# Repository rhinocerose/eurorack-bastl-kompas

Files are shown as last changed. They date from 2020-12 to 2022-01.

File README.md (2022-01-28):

# Cloned from https://git.sr.ht/~philomates/kompas

# SMD version of Bastl Kompas

As an attempt to learn kicad I decided to take the open source Bastl Kompas eurorack module, which is a 5hp through-hole soldering project, and redesign it as a 4hp SMD soldering project.

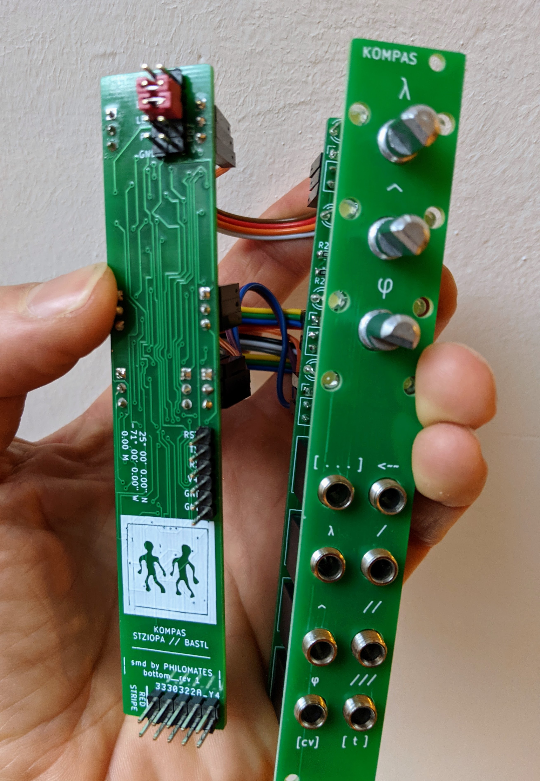
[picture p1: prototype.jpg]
prototype


## Bill of Materials

[Mouser BOM](https://www.mouser.de/ProjectManager/ProjectDetail.aspx?AccessID=1936c8aad0) or find the excel file in this repository.

Parts should come out to be below 20 euros.

## hardware modifications

The SMD version has a different pin mapping which should be described in the code. The reason for this is the following:

### exposing MOSI/MISO/SCK/SS for on-pcb bootloader flashing

With the original Kompas you can take the ATMEGA328 chip, place it on a breadboard, and flash the Arduino bootloader onto it by wiring the MOSI/MISO/SCK/SS pins up to a normal Arduino or another ISP programmer.
With the SMD ATMEGA328-AU chip, you can't put it on a breadboard, so the normal way for flashing these with the arduino bootloader

### exposing SDA/SCL pins as extension pins for integration with sensors

This project is based off the ATMEGA328-AU chip, which has 2 additional analog input pins when compared to the ATMEGA328-P that the Bastl Kompas uses.

### different pins

It is easiest to check the code or schematics. This was done to cleanly expose the ICSP headers and serial pins.

### more exposed pins for extensions

## hardware resources

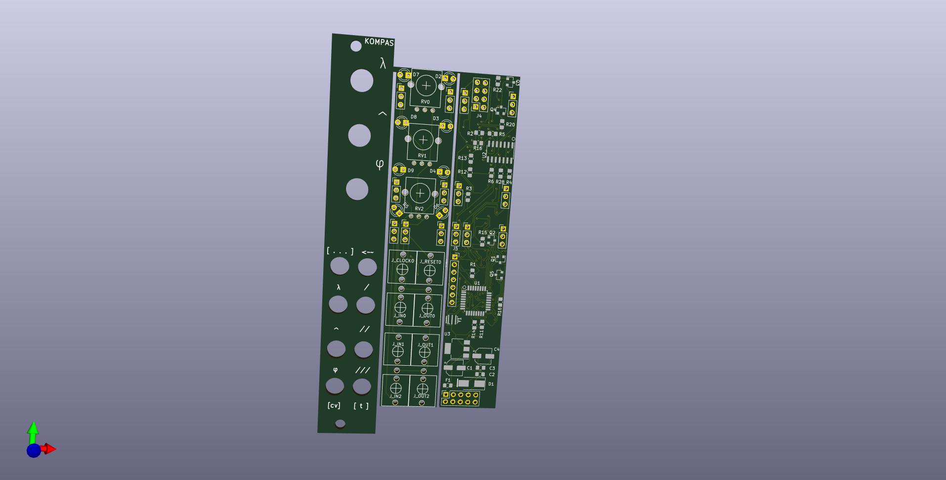
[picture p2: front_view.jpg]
front_view


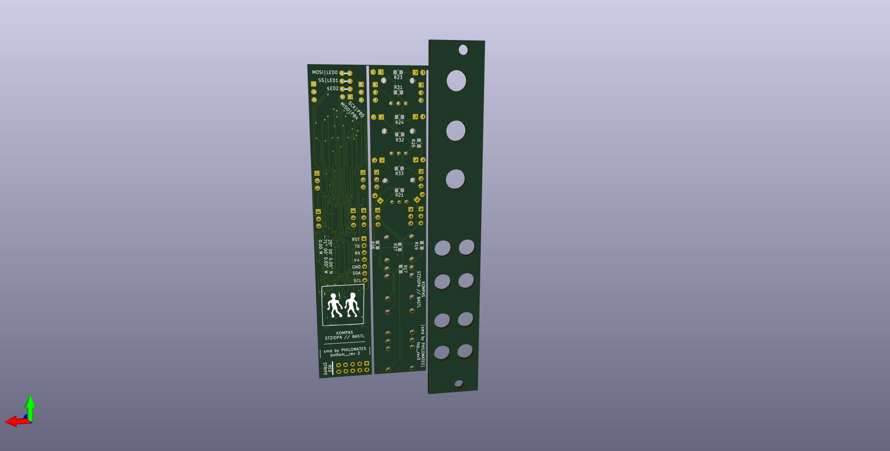
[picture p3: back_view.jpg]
back_view


[schematic found here](schematic.pdf)

The design was done in Kicad. Also provided are the gerber files for PCB fabrication

## alternative firmwares

See `code/` directory.

### window comparator

Essentially an attempt to be half of a Joranalogue 'Compare 2' module. Works alright and the top pot is mapped to a sample rate reduction thing which gives funky results.

### probabilistic latch / burst generator

Dual latch + single burst generator. The latches have probability modulation for likelihood of un/setting.

## CHANGELOG

### rev 3 (untested)

 - fixed up some alignments in the panel (I think)
 - removed second fuse (reducing parts cost by a 1 euro) because few people would use it

### rev 2
 - fixed missing connection issues in rev 1
 - ICSP header pins exposed for bootloader flashing
 - SDA/SCL serial line pins exposed for interfacing with other components

### rev 1
 - direct copy of Bastl version but in SMD.
 - has some bugs that require custom connections after.
 - flashing arduino bootloader requires soldering jumpers straight to SMD components.

## License

The original (Bastl Kompas)[https://github.com/bastl-instruments/kompas] is CC-BY-SA and this work perpetuates that.

Utmost thanks to the original designers for making their work available!

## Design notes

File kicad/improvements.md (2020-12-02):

expose for programming:
MOSI (PB3) 15
MISO (PB4) 16
SCK (PB5) 17
RESET (PC6) 29

expose for DAC
SS (PB2)

PB2 -- out1
PB3 -- out0
PB4 -- reset
PB5 -- clock

reset could go to PB0
clock could go to PD7
could switch outs with leds so you can choose between DAC or LEDs
could expose ADC6 (19) and ADC7 (22) for extra analog ins

PWM pins
PB1
PB2
PB3
PD3
PD5
PD6

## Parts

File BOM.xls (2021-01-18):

KOMPAS SMD
Mouser No | Mfr. No | Manufacturer | Customer No | Description | RoHS | Lifecycle | Order Qty. | Price (EUR) | Ext.: (EUR)
667-EEE-1EA100SR | EEE-1EA100SR | Panasonic | kC1, C4 | Aluminium Electrolytic Capacitors - SMD 10uF 25V | RoHS Compliant |  | 2 | 0,195 € | 0,39 €
80-C0805C104K5R | C0805C104K5RACTU | KEMET | kC2, C3 | Multilayer Ceramic Capacitors MLCC - SMD/SMT 50V 0.1uF X7R 0805 10% | RoHS Compliant |  | 2 | 0,203 € | 0,41 €
660-RK73H2ATTD1002F | RK73H2ATTD1002F | KOA Speer | k18,20,22 | Thick Film Resistors - SMD 1/4W 10K OHM 1% | RoHS Compliant |  | 3 | 0,101 € | 0,30 €
595-LM7805MPX/NOPB | LM7805MPX/NOPB | Texas Instruments | k | Linear Voltage Regulators | RoHS Compliant |  | 1 | 1,12 € | 1,12 €
621-S1KB-F | S1KB-13-F | Diodes Incorporated | kD1 | Rectifiers 800V 1A | RoHS Compliant By Exemption |  | 1 | 0,296 € | 0,30 €
621-MMBT3904-F | MMBT3904-7-F | Diodes Incorporated | k | Bipolar Transistors - BJT 40V NPN SS Trans 60Vceo 6Vebo 200mA | RoHS Compliant |  | 5 | 0,102 € | 0,51 €
579-MCP6004T-I/SL | MCP6004T-I/SL | Microchip | k | Operational Amplifiers - Op Amps Quad 1.8V 1MHz | RoHS Compliant |  | 1 | 0,373 € | 0,37 €
81-CSTNE16M0VH3L000R | CSTNE16M0VH3L000R0 | Murata | k | Resonators 16.0000MHz 15pF SMD CHP Resntr Tol 0.07% |  |  | 1 | 0,356 € | 0,36 €
576-0805L010/24YR | 0805L010/24YR | Littelfuse | k | Resettable Fuses - PPTC 0.10A 24V 0805 | RoHS Compliant |  | 1 | 1,58 € | 1,58 €
667-ERJ-6RED1004V | ERJ-6RED1004V | Panasonic | k2,3,28 | Thick Film Resistors - SMD 0805 Resistor 0.5% 100ppm 1MOhm |  |  | 3 | 0,178 € | 0,53 €
667-ERJ-6RBD1001V | ERJ-6RBD1001V | Panasonic | k11,12,14,15,17,19,21 | Thick Film Resistors - SMD 0805 1Kohms 0.5% AEC-Q200 | RoHS Compliant By Exemption |  | 15 | 0,065 € | 0,98 €
645-521-9901-802F | 521-9901-802F | Dialight | k | Standard LEDs - Through Hole White Octo-Binned | RoHS Compliant |  | 10 | 0,332 € | 3,32 €
556-ATMEGA328-AUR | ATMEGA328-AUR | Microchip | k | 8-bit Microcontrollers - MCU AVR 32K FLSH 1K EE2K SRAM-20MHz IND | RoHS Compliant |  | 1 | 1,61 € | 1,61 €
538-22-28-4360 | 22-28-4360 | Molex | k | Headers & Wire Housings 36P 1 ROW VERT HDR | RoHS Compliant |  | 2 | 0,686 € | 1,37 €
855-M7582-05 | M7582-05 | Harwin | k | Headers & Wire Housings JUMPER SOCKET OPEN TOP BLACK | RoHS Compliant |  | 4 | 0,169 € | 0,68 €
710-61301011821 | 61301011821 | Wurth Elektronik | k | Headers & Wire Housings WR-PHD 2.54mm 10Pin Socket Header | RoHS Compliant |  | 1 | 0,559 € | 0,56 €
660-RN732ATTD1003D25 | RN732ATTD1003D25 | KOA Speer | k1,4,5,6,13,16 | Thin Film Resistors - SMD 100kOhm 0805 0.5% 25 ppm 100mW 100V | RoHS Compliant |  | 6 | 0,181 € | 1,09 €
858-P0915NEC15BR100K | P0915N-EC15BR100K | TT Electronics |  | Potentiometers 9mm 100Kohm | RoHS Compliant |  | 3 | 1,02 € | 3,06 €

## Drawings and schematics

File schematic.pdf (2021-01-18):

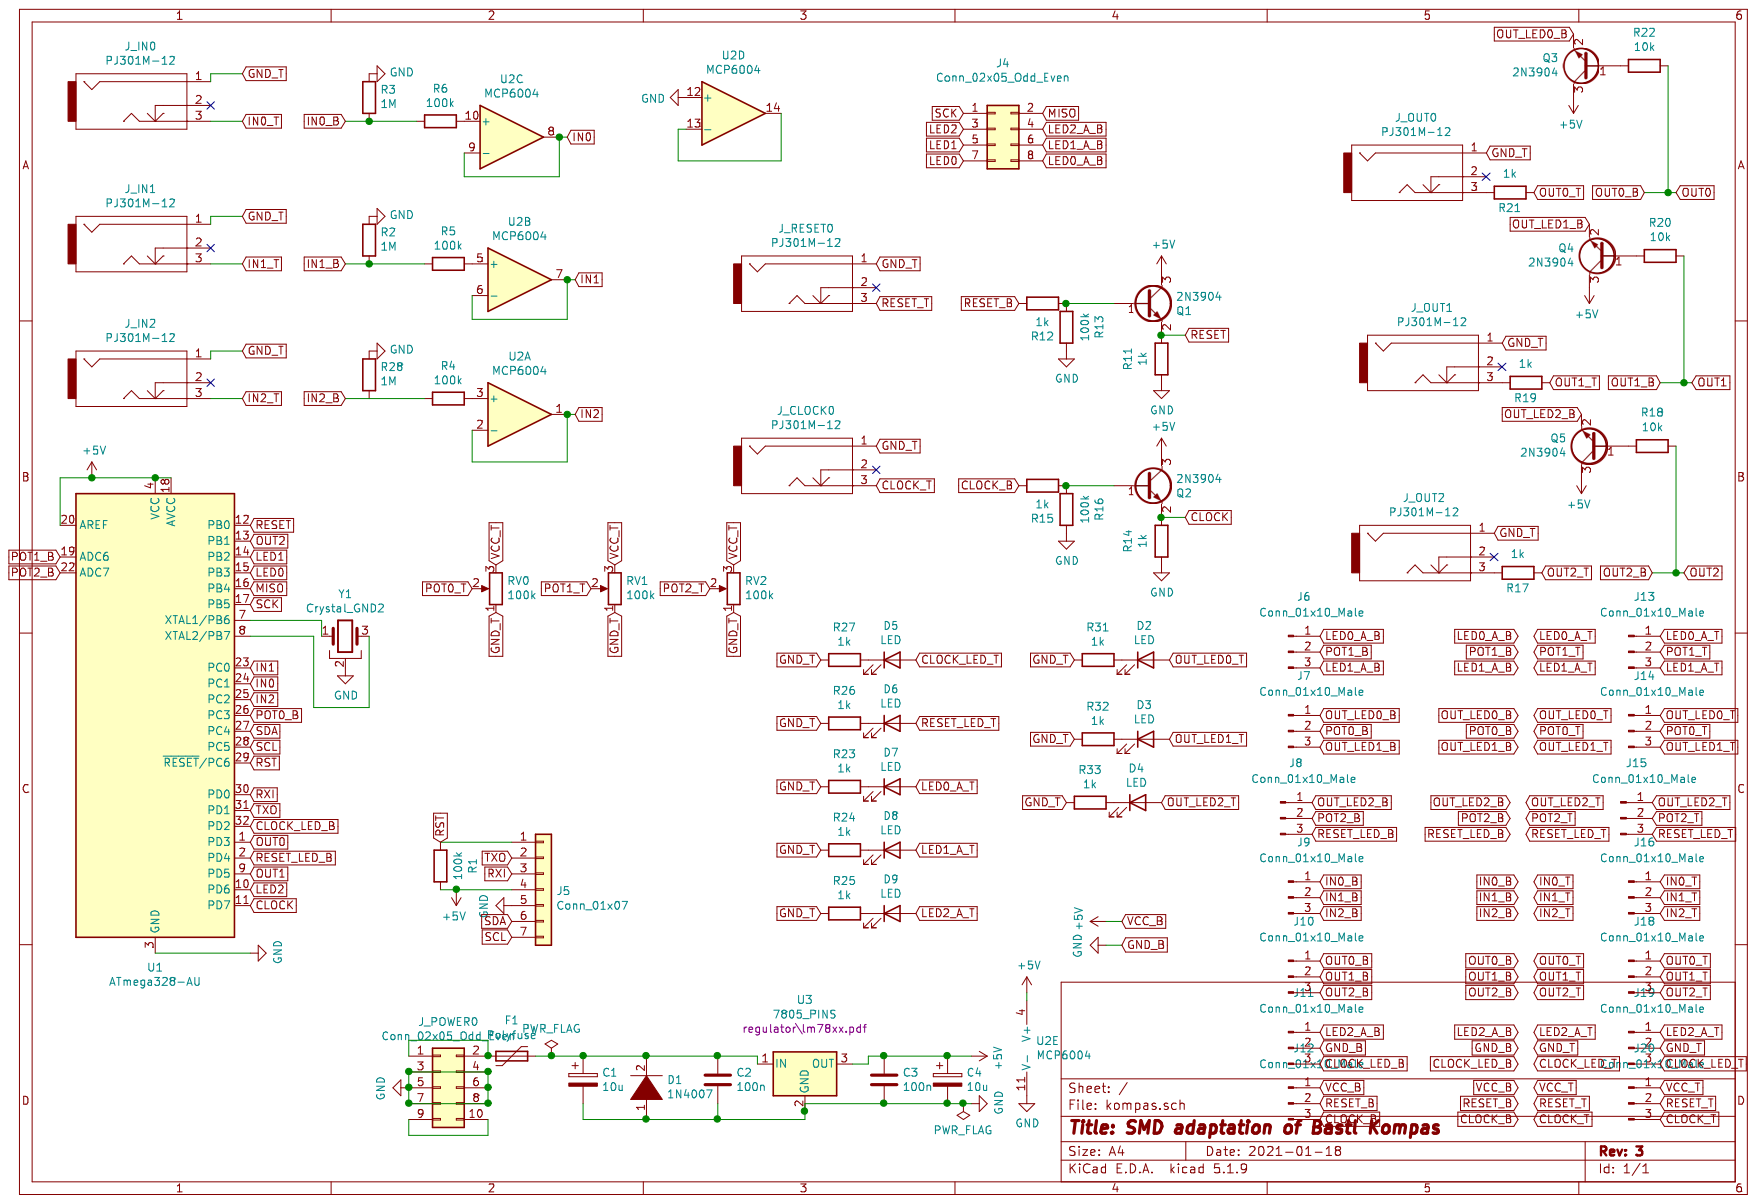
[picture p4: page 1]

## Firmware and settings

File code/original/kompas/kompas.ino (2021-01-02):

/*
 * Firmware for stziopa/bastl-instruments Kompas
 * licensed under CC-BY-SA by Stefano Manconi 02-09-2019
 */

/*
 * KOMPAS
 *
 *this tool is
 *the outcome
 *of the environment
 *we are in and
 *is inspired by a
 *non-linear approach
 *to music and life -
 *don't build any
 *expectations choose
 *your direction and
 *discover new paths
 *
*/

//NAVIGATION BEGINS:......
#include <EEPROM.h>
#include "hardware.h"
#include "definitions.h"
#include "variables.h"

void setup() {
  Serial.begin(9600);
  bootMode = false;
  //check for the first startup
  if(!isEEPROMvalid()){
    formatFactory();
    delay(100);
  }

  loadPreset();

  // set pins PB7, PB6, PB3 (led0), PB2 (led1), PB1 (out2) as outputs,
  // PB5, PB4, PB0 as input
  DDRB = B11001110;
  /* PORTB|B00000001; */
  // PB0 internal pullup resistor
  /* PINB|=B00000001; */

  // set PD7 as input
  DDRD= DDRD & B01111111;
  // set pins PD6, PD5, PD4, PD3, PD2 as outputs
  // leaves PD1 and PD0 as default (ftdi)
  DDRD = DDRD | B01111100;
  /* PORTD|B00000000; */
  // PD7 High
  /* PIND|=B10000000; */

  pinMode(clock_led, OUTPUT);
  pinMode(reset_led, OUTPUT);

  pinMode(led0, OUTPUT);
  pinMode(led1, OUTPUT);
  pinMode(led2, OUTPUT);

  randomSeed(analogRead(A5));

  //BOOTMODE (close jumper in between PB0 and GND before startup)
  if(!bootPin) {
    bootMode = true;
    loadPreset();

    pot0 = analogRead(A3);
    pot1 = analogRead(A4);
    pot2 = analogRead(A5);
    prevPot0 = pot0;
    prevPot1 = pot1;
    prevPot2 = pot2;

  } else {
    bootMode = false;
    loadPreset();
  }

  while(bootMode) {
    pot0 = analogRead(A3);
    pot1 = analogRead(A4);
    pot2 = analogRead(A5);

    if(pot0 > (prevPot0 + 9) || pot0 < (prevPot0 - 9)) {
      prevPot0 = pot0;
      EEPROM.update(addr, 0x0);
    }
    if(pot1 > (prevPot1 + 9) || pot1 < (prevPot1 - 9)) {
      prevPot1 = pot1;
      EEPROM.update(addr, 0x1);
    }
    if(pot2 > (prevPot2 + 9) || pot2 < (prevPot2 - 9)) {
      prevPot2 = pot2;
      EEPROM.update(addr, 0x2);
    }

  loadPreset();
  switch(trigPreset) {
      case 0:
        PORTD=PORTD&B11010111; // set Out{0,1} low
        PORTB=PORTB&B11111101; // set Out2 low
        PIND|=B00001000; // set Out0 high
        break;
      case 1:
        PORTD=PORTD&B11010111; // set Out{0,1} low
        PORTB=PORTB&B11111101; // set Out2 low
        PIND|=B00100000; // set Out1 high
        break;
      case 2:
        PORTD=PORTD&B11010111; // set Out{0,1} low
        PINB|=B00000010; // set Out2 high
        break;
  }
  //delay(100);
  //Serial.println(bootMode);
  }
  Serial.println(trigLength);
}

void loop() {

  //enables clock and reset functions
  deClock();
  deReset();

  generateArray0();
  generateArray2();
  generateArray1();
  //comment out for CV
  //deReset0();
  //deReset1();
  //deReset2();

  //global & individual resets
  if(resetState) {
    lastReset = millis();
    digitalWrite(reset_led, HIGH);
    step0 = (length0 - 1);
    step1 = (length1 - 1);
    step2 = (length2 - 1);
  }

  //un-comment for turning CV inputs into individual reset inputs!
  /*
  if(reset0State) {
    lastReset0 = millis();
    digitalWrite(led0, HIGH);
    step0 = (length0 - 1);
  }
  if(reset1State) {
    lastReset1 = millis();
    digitalWrite(led1, HIGH);
    step1 = (length1 - 1);
  }
  if(reset2State) {
    lastReset2 = millis();
    digitalWrite(led2, HIGH);
    step2 = (length2 - 1);
  }  */

//for each incoming clock detected:
  if(clockState) {
    lastClock = millis();
    step0++;
    step1++;
    step2++;

    digitalWrite(clock_led, HIGH);

    if(step0 > (length0 - 1)) {
      step0 = 0;
    }
    if(step1 > (length1 - 1)) {
      step1 = 0;
    }
    if(step2 > (length2 - 1)) {
      step2 = 0;
    }

    //current step number
    pos0 = step0;
    pos1 = step1;
    pos2 = step2;


    //read CV input Longitude, Altitude, Latitude
    cv0 = analogRead(A0);
    cv1 = analogRead(A1);
    cv2 = analogRead(A2);



    if(cv0 > 1011) {
      stepValue0 = 0;
      stepValue0 = 1;
      digitalWrite(led0, HIGH);
    } else {
      stepValue0 = 0;
      stepValue0 = patternArray0[pos0];
    }

    if(cv1 > 1011) {
      stepValue1 = 0;
      stepValue1 = 1;
      digitalWrite(led1, HIGH);
    } else {
      stepValue1 = 0;
      stepValue1 = patternArray1[pos1];
    }

    if(cv2 > 1011) {
      stepValue2 = 0;
      stepValue2 = 1;
      digitalWrite(led2, HIGH);
    } else {
      stepValue2 = 0;
      stepValue2 = patternArray2[pos2];
    }

    if(stepValue0) {
      PIND|=B00001000; // set Out0 high
    }
    if(stepValue1) {
      PIND|=B00100000; // set Out1 high
    }
    if(stepValue2) {
      PINB|=B00000010; // set Out2 high
    }

    //read values from pots Longitude, Altitude, Latitude
    pot0 = analogRead(A3);
    pot1 = analogRead(A6);
    pot2 = analogRead(A7);

    //add CV to pot value (offset)
    prob0 = (pot0 + cv0);
    prob1 = (pot1 + cv1);
    prob2 = (pot2 + cv2);
    Serial.println(String(cv0) + "\t" + String(cv1) + "\t" + String(cv2)
    + "\t" + String(pot0) + "\t" + String(pot1) + "\t" + String(pot2));


    noSteps0 = map(prob0, 1, 1021, 1, 8);

  }

  // sets the end of trigger signals and clock LED
  if(millis() >= lastClock + trigLength) {
    PORTD=PORTD&B11010111; // set Out{0,1} low
    PORTB=PORTB&B11111101; // set Out2 low
    digitalWrite(clock_led, LOW);
  }

  // LONGITUDE randomarray over euclidean
    if(prob0 > (prevProb0 + 2) || prob0 < (prevProb0 - 2)) {
      prevProb0 = prob0;

    if(prob0 > 2) {
    if(prob0 < 1011) {
      generate0 = true;

      patternArray0[0] = 1;
      for(int i=1; i<(length0/2); i++) {
          if(((i*noSteps0)%(length0/2)) < noSteps0) {
            patternArray0[i] = 1;
            if((randomArray0[i] < prob0) & patternArray0[i]) {
              patternArray0[i] = 1;
            } else {
              patternArray0[i] = 0;
            }
          } else {
            patternArray0[i] = 0;
          }
        }
      for(int i=(length0/2); i<length0; i++) {
          if(((i*noSteps0)%(length0/2)) < noSteps0) {
            patternArray0[i] = 1;
            if((randomArray0[i] < prob0) & patternArray0[i]) {
              patternArray0[i] = 1;
            } else {
              patternArray0[i] = 0;
            }
          } else {
            patternArray0[i] = 0;
          }
        }

      }

      } else {
          for(int i=0; i < length0; i++) {
          patternArray0[i] = 0;
          }
          }

      if(pot0 > 1011) {
        for(int i=0; i < length0; i++) {
          patternArray0[i] = 1;
          }
      }

}


  // LATITUDE pseudo-random array
    if(prob2 > (prevProb2 + 2) || prob2 < (prevProb2 - 2)) {
      prevProb2 = prob2;

        if(prob2 > 2) {
         if(prob2 < 1011) {
         generate2 = true;

        for(int i=0; i < length2; i++) {
          if(randomArray2[i] < (prob2)) {
              patternArray2[i] = 1;
            } else {
              patternArray2[i] = 0;
            }
          }

          //makes sure at least one step will be filled
          int rnd2 = random(length2);
          patternArray2[rnd2] = 1;

         }

      } else {
          for(int i=0; i < length2; i++) {
          patternArray2[i] = 0;
          }
          prevProb2 = 0;
        }

         if(pot2 > 1011) {
        for(int i=0; i < length2; i++) {
          patternArray2[i] = 1;
          }
      }
  }


  // ALTITUDE if Long == Lat - it makes a pattern based on matching steps
    if(prob1 > (prevProb1 + 2) || prob1 < (prevProb1 - 2)) {
      prevProb1 = prob1;

       if(prob1 > 2) {
       if(prob1 < 1011) {
        generate1 = true;

        for(int i=0; i < length1; i++) {
            if(patternArray0[i] == patternArray2[i]) {
              if(randomArray1[i] < prob1) {
                patternArray1[i] = 1;
              } else {
                patternArray1[i] = 0;
              }
            } else patternArray1[i] = 0;
          }

        for(int i=0; i < length1; i++) {
            if(patternArray0[i] == patternArray2[i]) {
                patternArray1[i] = 1;
                i = length1;
              }
            }

        }

       } else {
          for(int i=0; i < length1; i++) {
            patternArray1[i] = 0;
          }
        }

         if(pot1 > 1011) {
        for(int i=0; i < length1; i++) {
          patternArray1[i] = 1;
          }
      }
}


  //turn off reset LED
  if(millis() >= lastReset + trigLength) {
    digitalWrite(reset_led, LOW);
  }
  //turn off coordinate LEDs
  if(millis() >= lastGenerate0 + trigLength) {
  digitalWrite(led0, LOW);
  }
  if(millis() >= lastGenerate1 + trigLength) {
    digitalWrite(led1, LOW);
  }
  if(millis() >= lastGenerate2 + trigLength) {
    digitalWrite(led2, LOW);
  }
}

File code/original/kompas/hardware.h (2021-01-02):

#ifndef _HARDWARE_H_
#define _HARDWARE_H_

//Kompas Hardware

#define clockIn PIND&B10000000
#define resetIn PINB&B00000001

//un-comment for turning CV inputs into individual reset inputs
//#define resetIn0 PINC&B00000001
//#define resetIn1 PINC&B00000010
//#define resetIn2 PINC&B00000100

//Port mapping for outputs Longitude, altitude, latitude
#define trigOut0 PIND&B00001000 // PD3
#define trigOut1 PIND&B00100000 // PD5
#define trigOut2 PINB&B00000010 // PB1

//unused pins (see expander header on bottom board)
#define PB4 PINB&B00010000
#define PB5 PINB&B00100000

// Mapping of LEDs
int clock_led = 2;
int reset_led = 4;
int led2 = 6;
int led1 = 10;
int led0 = 11;

//expander pin for Boot Settings
#define bootPin PINB&B00010000

#endif

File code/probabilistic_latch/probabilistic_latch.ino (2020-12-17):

/*
   Alternative probabilistic latch / burst firmware for stziopa/bastl-instruments Kompas hardware
   licensed under CC-BY-SA by Phillip Mates 2020-12-11

knobs
-------------
(burst count)  o
(latch A prob) o
(latch B prob) o

jacks
-------------
(burst trigger)     o  |  o   (latch A trigger)
(burst length)      o  |  o   (burst out)
(latch A prob)      o  |  o   (latch A out
(latch B trigger)   o  |  o   (latch B out)
*/

#include <EEPROM.h>
#include "hardware.h"
#include "definitions.h"
#include "variables.h"

void setup() {
  Serial.begin(9600);

  // set pins PB7, PB6, PB3, PB2, PB1  as outputs, PB0 as input
  DDRB = B11001110;
  PORTB | B00000001;
  // PB0 internal pullup resistor
  PINB |= B00000001;

  // set pins PD7, PD6, PD5, PD4, PD3, PD2 as outputs, leaves PD1 and PD0 as default (ftdi)
  DDRD = DDRD | B11111100;
  PORTD | B00000000;
  // PD7 High
  PIND |= B10000000;

  pinMode(burst_in_led, OUTPUT);
  pinMode(latch_a_in_led, OUTPUT);

  pinMode(led0, OUTPUT);
  pinMode(led1, OUTPUT);
  pinMode(led2, OUTPUT);

  randomSeed(analogRead(A5));
}

bool latchAOn, latchBOn;
uint8_t burstLengthBase = 100;
uint8_t burstCount, burstsLeft, burstLength;
unsigned long now;

void loop() {
  deLatchATrig();
  deBurstTrig();
  deLatchBTrig();
  latchAOn = trigOut1;
  latchBOn = trigOut2;
  now = millis();

  // on my hardware the top cv in is A1
  burstCV = analogRead(A1);
  latchACV = analogRead(A0);

  // read values from pots
  burstPot = analogRead(A3);
  latchAPot = analogRead(A4);
  latchBPot = analogRead(A5);

  int rnd = random(1011);

  if (latchAState) {
    digitalWrite(latch_a_in_led, HIGH);
    lastLatchA = now;
    if (!(!(trigOut1))) {
      // latch off
      PORTB &= B11111011;
    } else if ((latchAPot + latchACV) > rnd) {
      // latch on
      PINB |= B00000100;
    }
  }
  if (now >= lastLatchA + trigLength) {
    digitalWrite(latch_a_in_led, LOW);
  }

  if (latchBState) {
    lastLatchB = now;
    if (!(!(trigOut2))) {
      // latch off
      PORTB &= B11111101;
    } else if (latchBPot > rnd) {
      // latch on
      PINB |= B00000010;
    }
  }

  burstCount = burstPot / 128;
  burstLength = burstLengthBase + ((burstCV / 64) * burstLengthBase);

  // start bursts
  if (burstState) {
    burstsLeft = burstCount;
    lastBurstIn = now;
    digitalWrite(burst_in_led, HIGH);
  }

  // turn off burst in LED
  if (now >= lastBurstIn + trigLength) {
    digitalWrite(burst_in_led, LOW);
  }

  // trigger a burst
  if ((burstsLeft > 0) && (now >= (lastBurst + burstLength))) {
    lastBurst = now;
    burstsLeft--;
    PINB |= B00001000;
  }

  // shut off a single burst
  if (now >= lastBurst + trigLength) {
      PORTB &= B11110111;
  }
}

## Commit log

2020-11-28 v1 of kicad
    [kompas-B_Cu.gbr, kompas-B_Mask.gbr, kompas-B_SilkS.gbr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]
2020-11-28 fix transistors
    [kompas.kicad_pcb]
2020-11-28 adapt headers
    [kompas.kicad_pcb, kompas.sch]
2020-11-28 add SS header
    [kompas.kicad_pcb, kompas.sch]
2020-12-02 fixup reset pin
    [kompas.kicad_pcb, kompas.sch]
2021-01-18 add gerbers
2021-01-18 add some libs
    [kompas.kicad_pcb, kompas.sch]
2021-01-18 update readme + bom
    [BOM.xls]
2025-08-12 Update submodules to track main branch
